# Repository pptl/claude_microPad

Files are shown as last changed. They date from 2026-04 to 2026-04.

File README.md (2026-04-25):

# Claude Ghost Macro Pad 專案計畫書 (V2.0 雙層鍵帽版)

這是一台專為 **Claude Code** 開發流程優化的左手專用巨集鍵盤。本版本採用 **雙層透明鍵帽 (Relegendable Keycaps)** 方案，透過紙條替換實現快速客製化，無需轉印與噴漆。

外殼採鬼魂造型，橙色3D列印外殼，頂部兩顆 RGB LED 作為「鬼眼」狀態燈。閑置時會顯示綠色，思考時會顯示藍色，等待使用者確認權限時會顯示紅色。

成品展示

### LED 狀態展示

| 待機（Idle）| 思考中（Thinking）| 等待授權（Permission Request）|
| :---: | :---: | :---: |
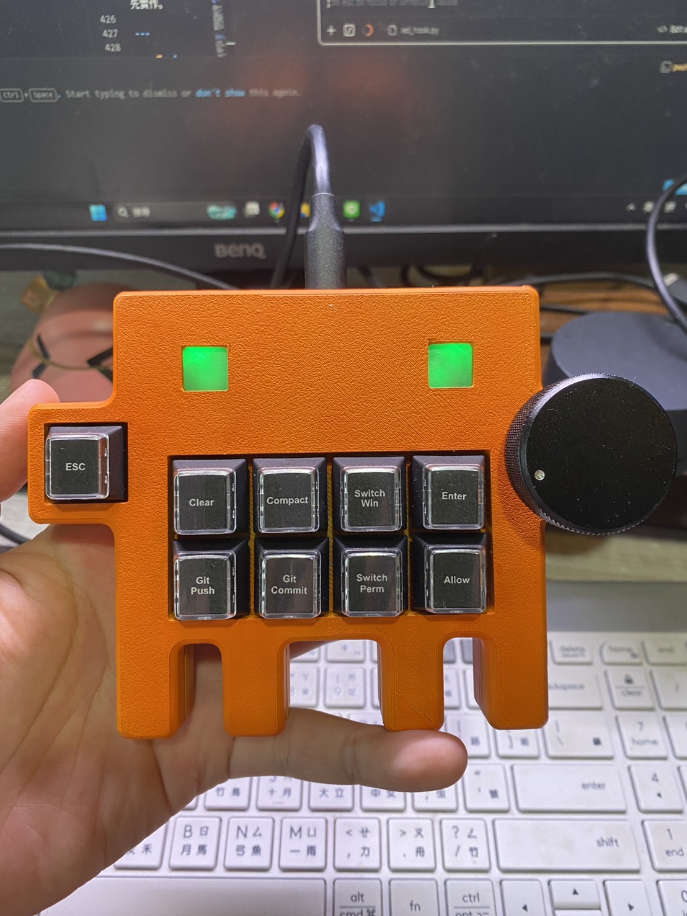
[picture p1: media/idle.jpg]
待機
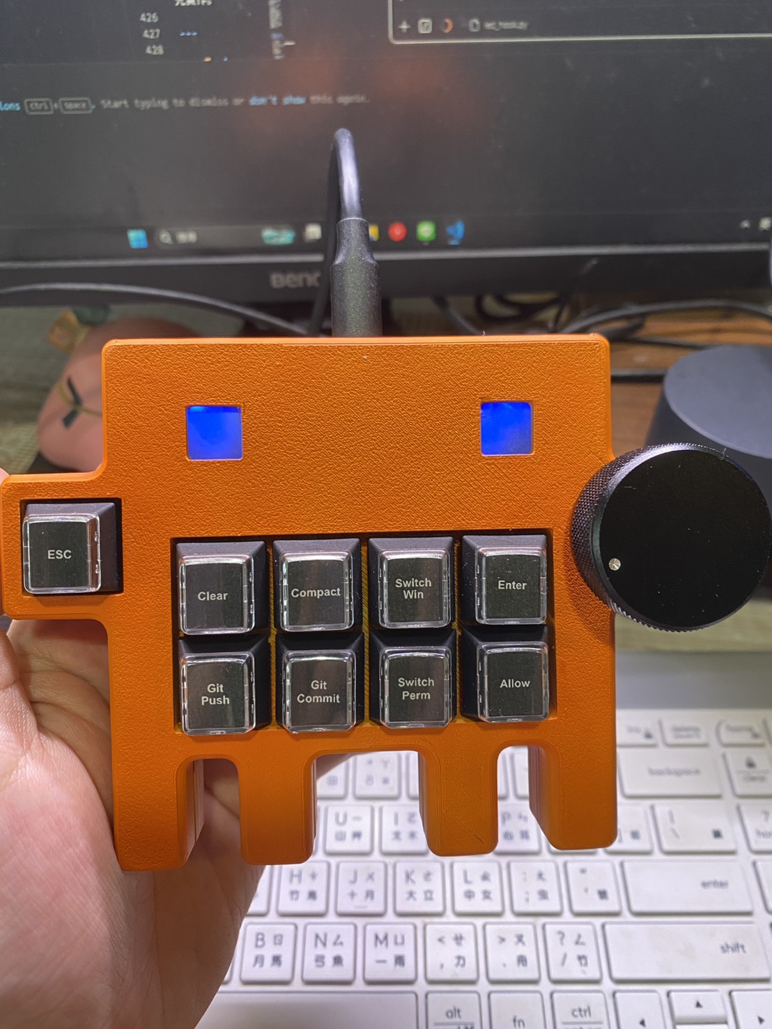
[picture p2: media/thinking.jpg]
思考中
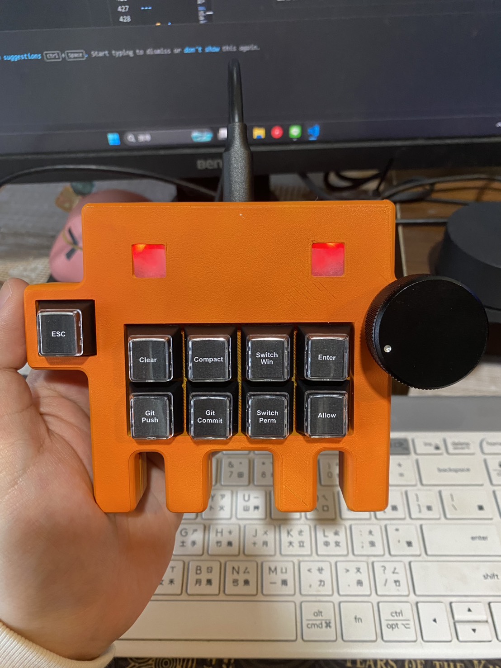
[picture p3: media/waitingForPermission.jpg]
等待授權
|  |  |  |
| 🟢 綠色 — 無操作 | 🔵 藍色 — Claude 執行工具中 | 🔴 紅色 — 等待使用者確認 |

---

## 🛠️ 一、 核心硬體採購清單

| 項目 | 購買規格 | 關鍵規格說明 | 備註 |
| :--- | :--- | :--- | :--- |
| **控制器** | **YD-RP2040** | Raspberry Pi Pico 相容 / Type-C 介面 | 核心開發板 |
| **指示燈** | **5mm RGB LED × 2** | 共陽極 / 四腳 / 透明 | 用於鬼魂眼睛，低電位觸發 |
| **機械軸** | **靜音系列** | 高特青檸軸 V3 / TTC 靜音紅 V3 | 靜音開發專用 |
| **鍵帽** | **雙層透明鍵帽** | 1U Relegendable Keycaps（共 9 顆） | 可拆卸頂蓋，內放紙條 |
| **編碼器** | **EC11 旋鈕** | D 型半軸 / 柄長 15mm / 帶開關 | 30 脈衝版本 |
| **旋鈕帽** | **大型全鋁** | 35×16mm 黑色滾花噴砂 | 直徑 35mm |
| **數據綫** | **TypeA to TypeC** | 長度按需求選購 |
| **線材** | **30 AWG 矽膠線** | 超軟、多色套裝 | 內部焊接理線專用 |
| **螺絲** | **M2 × 6mm 平頭螺絲** | 平頭（沉頭）/ 不鏽鋼或黑色 | 上下蓋固定用 |
| **止滑貼片** | **自黏橡膠腳墊 × 6** | 圓形或方形均可 | 底部墊高及止滑 |

---

## ⌨️ 二、 鍵盤佈局

按鍵位置示意圖（與 `keymap.h` 索引對應）：

```
[ 8 ]                                        [ 9 ] ← 旋鈕按下
         [ 0 ]    [ 1 ]    [ 2 ]    [ 3 ]
         [ 4 ]    [ 5 ]    [ 6 ]    [ 7 ]
```

全按鍵均為 1U 規格，目前預設按鍵功能如下：

| 索引 | 位置 | 功能 | 輸出 |
| :--- | :--- | :--- | :--- |
| **[8]** | 左上角獨立鍵 | ESC | ESC |
| **[9]** | 右上角旋鈕按下 | Enter | Enter |
| **[0]** | 矩陣上排 1 | Clear 對話 | `/clear` + Enter |
| **[1]** | 矩陣上排 2 | Compact 對話 | `/compact` + Enter |
| **[2]** | 矩陣上排 3 | Switch Window | Win+Tab |
| **[3]** | 矩陣上排 4 | Enter | Enter |
| **[4]** | 矩陣下排 1 | Git Push | `/gitPush` + Enter |
| **[5]** | 矩陣下排 2 | Git Commit | `/gitCommit` + Enter |
| **[6]** | 矩陣下排 3 | Change Permission Mode | Shift+Tab |
| **[7]** | 矩陣下排 4 | Allow | `allow` + Enter |
| — | 旋鈕旋轉 | 捲動 | ↑ / ↓ |

---

## 🔌 三、 電路設計

### WOKWI 可查看電路設計圖

將 `diagram.json` 的內容全部貼到 [WOKWI](https://wokwi.com) 上可以查看整體電路設計圖。

### GPIO 接腳對照（與韌體一致）

| GPIO | 功能 |
| :--- | :--- |
| GP0 | 按鍵 [8] — ESC |
| GP2 | LED1 R（左眼）|
| GP3 | LED1 G（左眼）|
| GP4 | LED1 B（左眼）|
| GP6 | 按鍵 [0] — Slash (`/`) |
| GP7 | 按鍵 [1] — Shift+Tab |
| GP8 | 按鍵 [4] — /gitPush |
| GP9 | 按鍵 [5] — claude |
| GP16 | 按鍵 [2] — Win+Tab |
| GP17 | 按鍵 [3] — Enter |
| GP18 | 按鍵 [7] — /compact |
| GP19 | 按鍵 [6] — /clear |
| GP20 | Encoder CLK |
| GP21 | Encoder DT |
| GP22 | 按鍵 [9] — Encoder SW (ESC) |
| GP26 | LED2 B（右眼）|
| GP27 | LED2 G（右眼）|
| GP28 | LED2 R（右眼）|

### LED 接線（共陽極）

- 最長腳（COM）→ 3.3V
- R、G 腳各串 **220Ω** 電阻後接 GPIO
- B 腳串 **68Ω** 電阻後接 GPIO（藍光 Vf 較高，需降低電阻）
- 軟體邏輯：`LOW` = 亮，`HIGH` = 滅

### 去耦電容（實體焊接）

手邊有 3 顆 **10µF** 電容，分別焊接於：
- LED1 電源入口旁（3.3V ↔ GND）
- LED2 電源入口旁（3.3V ↔ GND）
- 編碼器旁（3.3V ↔ GND）

防止 LED 切換時的 Ground Bounce 干擾按鍵與編碼器訊號。

### 關鍵尺寸限制

旋鈕中心至 Enter 鍵中心距離必須 **> 27mm**，避免 35mm 旋鈕帽碰撞。

---

## 💡 四、 LED 狀態指示

兩顆鬼眼 LED 即時反映 Claude Code 的工作狀態：

| 狀態 | 顏色 | 說明 |
| :--- | :--- | :--- |
| Idle（待機）| 🟢 綠色 | 開機預設、無操作、任務被使用者中斷（ESC）或拒絕授權 |
| Thinking（思考中）| 🔵 藍色 | Claude 正在執行工具 |
| Completed（完成）| 🟢 綠色 | 任務完成、回覆結束或 `/compact` 壓縮完畢 |
| Waiting（等待授權）| 🔴 紅色 | 等待使用者批准工具使用請求（PermissionRequest）|
| Error（問題）| 🔴 紅色 | 工具失敗、API 錯誤 |

---

## 💻 五、 安裝方法與步驟

### 步驟一：燒錄韌體（Arduino IDE）

1. 安裝 **Arduino IDE**（1.8 或 2.x）

2. 開啟 Preferences，在 **Additional Boards Manager URLs** 加入：
   ```
   https://github.com/earlephilhower/arduino-pico/releases/download/global/package_rp2040_index.json
   ```

3. 至 **Tools → Board → Boards Manager**，搜尋並安裝 `Raspberry Pi RP2040 Boards`

4. 至 **Sketch → Include Library → Manage Libraries**，搜尋並安裝 `Adafruit TinyUSB Library`

5. **Tools 設定：**
   - Board：`Raspberry Pi Pico`
   - USB Stack：`Adafruit TinyUSB`

6. 開啟 `firmware/claude_macropad/claude_macropad.ino`

7. **燒錄方式：** 按住 YD-RP2040 上的 **BOOT** 按鈕後插上 USB，放開後裝置會顯示為隨身碟，在 Arduino IDE 按 **Upload** 即可。

8. 燒錄成功後，鬼眼 LED 會閃爍三次藍光，然後轉為綠色待機。

### 步驟二：安裝 Python 依賴

```bash
pip install pyserial
```

### 步驟三：設定 COM Port

1. 插上 Macro Pad，開啟 **裝置管理員 → 連接埠 (COM 和 LPT)**，找到 RP2040 對應的 COM 編號

   > **快速辨識方法：** 在 Python 執行以下指令，找到 VID `0x239A`（Adafruit）的裝置即是 RP2040：
   > ```python
   > import serial.tools.list_ports
   > for p in serial.tools.list_ports.comports():
   >     print(p.device, hex(p.vid) if p.vid else "N/A", p.description)
   > ```

2. 修改 `hooks/led_hook.py` 第 19 行，填入實際 COM 編號：
   ```python
   PORT = "COM8"  # 依實際裝置調整
   ```

### 步驟四：設定 Claude Code Hooks

`led_hook.py` **沒有固定存放路徑**，可以放在任何位置，但必須確保 `~/.claude/settings.json` 裡的路徑與實際位置一致。

將以下內容加入 `~/.claude/settings.json`。`led_hook.py` 建議存放至全域 `~/.claude/scripts/` 資料夾，路徑需與本機使用者名稱一致（將 `USER_NAME` 替換為自己的帳號名稱）：

```json
{
  "hooks": {
    "UserPromptSubmit":   [{"matcher": "", "hooks": [{"type": "command", "command": "py C:\\Users\\USER_NAME\\.claude\\scripts\\led_hook.py"}]}],
    "PreToolUse":         [{"matcher": "", "hooks": [{"type": "command", "command": "py C:\\Users\\USER_NAME\\.claude\\scripts\\led_hook.py"}]}],
    "PostToolUse":        [{"matcher": "", "hooks": [{"type": "command", "command": "py C:\\Users\\USER_NAME\\.claude\\scripts\\led_hook.py"}]}],
    "Stop":               [{"matcher": "", "hooks": [{"type": "command", "command": "py C:\\Users\\USER_NAME\\.claude\\scripts\\led_hook.py"}]}],
    "PostToolUseFailure": [{"matcher": "", "hooks": [{"type": "command", "command": "py C:\\Users\\USER_NAME\\.claude\\scripts\\led_hook.py"}]}],
    "StopFailure":        [{"matcher": "", "hooks": [{"type": "command", "command": "py C:\\Users\\USER_NAME\\.claude\\scripts\\led_hook.py"}]}],
    "PermissionDenied":   [{"matcher": "", "hooks": [{"type": "command", "command": "py C:\\Users\\USER_NAME\\.claude\\scripts\\led_hook.py"}]}],
    "Notification":       [{"matcher": "", "hooks": [{"type": "command", "command": "py C:\\Users\\USER_NAME\\.claude\\scripts\\led_hook.py"}]}],
    "PermissionRequest":  [{"matcher": "", "hooks": [{"type": "command", "command": "py C:\\Users\\USER_NAME\\.claude\\scripts\\led_hook.py"}]}],
    "PostCompact":        [{"matcher": "", "hooks": [{"type": "command", "command": "py C:\\Users\\USER_NAME\\.claude\\scripts\\led_hook.py"}]}]
  }
}
```

> **注意：** Windows 使用 `py` 啟動器（上方範例），macOS / Linux 改用 `python3`。若移動了 `led_hook.py`，記得同步更新 settings.json 裡的路徑。

#### 偵錯：確認 Hook 是否正常運作

Hook 執行時會將收到的事件記錄至 `hooks/debug.log`。若 LED 無反應，可查看此檔案確認 Hook 是否有被觸發：

```bash
# 查看最後 10 筆事件
tail -10 d:/projects/claude_microPad/hooks/debug.log   # 原始專案路徑
# 或（若已移至全域）
tail -10 "C:/Users/USER_NAME/.claude/scripts/debug.log"
```

若 log 有內容但 LED 仍無反應，通常是 COM Port 設定錯誤或裝置未連接。

---

## 🎛️ 六、 自訂按鍵（keymap.h）

所有按鍵功能集中定義在 `firmware/claude_macropad/keymap.h`，**只需編輯此檔案，重新上傳韌體即可生效**，不需改動主程式。

### 按鍵索引對照

```
[ 8 ]                                        [ 9 ] ← 旋鈕按下
         [ 0 ]    [ 1 ]    [ 2 ]    [ 3 ]
         [ 4 ]    [ 5 ]    [ 6 ]    [ 7 ]
```

### 兩種按鍵模式

**模式一：組合鍵（BTN_KEYS）** — 送出單次按鍵或組合鍵

```c
const uint8_t BTN_KEYS[10][3] = {
  {SLASH, 0,      0},  // [0] /
  {SHIFT, TAB,    0},  // [1] Shift+Tab
  {WIN,   TAB,    0},  // [2] Win+Tab
  {ENTER, 0,      0},  // [3] Enter
  ...
};
```

**模式二：文字巨集（BTN_MACROS）** — 逐字輸出一串字元

```c
const char* BTN_MACROS[10] = {
  "/clear\n\n",     // [0] 輸出 /clear 後按兩次 Enter
  "/compact\n\n",   // [1] 輸出 /compact 後按兩次 Enter
  "",               // [2] 空字串 → 使用 BTN_KEYS
  "",               // [3] 空字串 → 使用 BTN_KEYS
  "/gitPush\n\n",   // [4] 輸出 /gitPush 後按兩次 Enter
  "/gitCommit\n\n", // [5] 輸出 /gitCommit 後按兩次 Enter
  "",               // [9] 空字串 → 使用 BTN_KEYS（旋鈕按下 = Enter）
  ...
};
```

> 若 `BTN_MACROS[i]` 非空字串，優先執行巨集，忽略 `BTN_KEYS[i]`。

### 可用按鍵常數

| 類別 | 常數 | 說明 |
| :--- | :--- | :--- |
| 修飾鍵 | `CTRL` `SHIFT` `ALT` `WIN` | Ctrl / Shift / Alt / Win |
| 方向鍵 | `UP` `DOWN` `LEFT` `RIGHT` | 上 / 下 / 左 / 右 |
| 特殊鍵 | `ENTER` `ESC` `TAB` `SPACE` `DEL` `BACKSPACE` `SLASH` | 常用功能鍵 |
| 字母鍵 | `L('a')` ~ `L('z')` | 例如 `L('e')` = E 鍵 |
| 數字鍵 | `N0` ~ `N9` | 例如 `N5` = 數字 5 |

> ⚠️ 不可直接用 `'c'` 或 `5`，ASCII 碼 ≠ USB HID 按鍵碼。

### 範例：改成自己的快捷鍵

```c
// 把 [3] 改成 Ctrl+Shift+P（命令選單）
{CTRL, SHIFT, L('p')},  // [3]

// 把 [6] 改成輸出自訂命令並送出
"/mycommand\n\n",  // [6] BTN_MACROS

// 把 [7] 改成單獨數字鍵
{N5, 0, 0},  // [7] BTN_KEYS（記得把 BTN_MACROS[7] 清空為 ""）
```

修改後，在 Arduino IDE 重新上傳韌體即可。

---

## ⚠️ 七、 製作提醒

1. **旋鈕高度差：** 雙層鍵帽比一般鍵帽略高，若旋鈕帽太矮難以轉動，可在旋鈕底部墊入 1–2mm 墊圈。
2. **標籤防褪色：** 有透明蓋保護，但長時間日光照射仍會褪色，建議多印幾份備用。
3. **線路固定：** 外殼半透明，內部焊接建議使用熱縮套管或熱熔膠固定，讓內視效果整齊。
4. **標籤尺寸：** 11mm × 13mm，上方功能名稱，下方小字快捷鍵，建議使用相片紙或名片紙。專案已附上可直接列印的 `Keycap_Labels_Print.pdf`，裁切後直接放入鍵帽即可。
5. **中文輸入法注意：** 巨集中的 `\n` 在開啟中文輸入法時可能被吃掉一個，建議使用 `\n\n` 確保指令送出。

---

## 📁 八、 專案檔案結構

```
claude_microPad/
├── README.md                          # 本文件
├── CLAUDE.md                          # Claude Code 專案指引
├── diagram.json                       # Wokwi 電路模擬圖
├── 按鈕佈局.drawio                     # 按鍵佈局設計圖（Draw.io）
├── Keycap_Labels_Print.pdf            # 🖨️ 鍵帽標籤列印檔（直接列印、裁切即可使用）
├── media/                             # 圖片、影片、GIF 媒體素材
│   ├── 按鈕佈局.jpg                   # 按鍵佈局匯出圖
│   ├── 成品展示_gif.gif               # 成品展示動圖
│   ├── 成品展示_pic.jpg               # 成品展示靜態圖
│   ├── fidgetToy.gif                  # 解壓玩具展示動圖
│   ├── demo.mp4                       # 成品展示影片
│   ├── idle.jpg                       # LED 狀態：待機
│   ├── thinking.jpg                   # LED 狀態：思考中
│   ├── waitingForPermission.jpg       # LED 狀態：等待授權
│   └── Gemini_Generated_Image_uxtut7uxtut7uxtu.png
├── firmware/
│   └── claude_macropad/
│       ├── claude_macropad.ino        # Arduino 韌體主程式（勿需修改）
│       └── keymap.h                   # ✏️ 按鍵自訂設定（在這裡修改）
└── hooks/
    └── led_hook.py                    # Claude Code Hook 腳本（設定 COM port）
```

---

---

## 🤖 九、 自訂 Slash Command — `/gitCommit`

本專案內建自訂 Claude Code 指令 `/gitCommit`，對應鍵盤上的 **[5]** 號按鍵。

### 功能說明

按下按鍵後，Claude Code 會自動：

1. **平行**收集 `git status`、`git diff HEAD`、`git log --oneline -5`、`git stash list`
2. 產出一份**繁體中文**的變更摘要（每個檔案說明改了什麼、為什麼），並建議符合此 repo 慣例的英文 commit 訊息
3. 顯示目前 git 帳號與分支，**等待用戶確認**後才執行寫入
4. 逐一 `git add` 相關檔案（避免加入敏感檔），再以 HEREDOC 執行 `git commit`
5. 回報最新 commit hash

> 收到確認之前，不會執行任何 git 寫入操作。

**例外處理：**
- 無變更 → 告知工作目錄乾淨
- 偵測到 `.env`、`*secret*` 等敏感檔 → 警告並略過
- pre-commit hook 失敗 → **不使用 `--amend`**，修正後建立全新 commit
- 殘留 Merge conflict 標記 → 中斷並警告

### 指令檔案位置

```
.claude/commands/gitCommit.md   ← 本專案專屬（僅此專案有效）
```

---

## 🤖 十、 自訂 Slash Command — `/gitPush`

本專案內建自訂 Claude Code 指令 `/gitPush`，對應鍵盤上的 **[9]** 號按鍵（旋鈕按下）。

### 功能說明

`/gitPush` 專責將已 commit 的變更推送至遠端，執行流程如下：

**第一階段：預檢**
- 若工作區有未提交的變更，**立即中斷**並提示先完成 commit 或 `git stash`
- 若分支尚無遠端追蹤（首次推送），跳至「首次推送流程」

**第二階段：狀態彙整**
- 顯示目前 git 帳號、分支，以及所有待推送的 commit 清單
- 若目前分支為 `main` / `master`，額外顯示保護分支警告

**第三階段：合併策略**

列出待推送 commit 後，提供三個選項：

| 選項 | 說明 |
| :--- | :--- |
| **1. 合併推送（預設）** | Squash 成單一 commit，自動建立備份分支 `backup/<branch>-<YYYYMMDD>` |
| **2. 編輯訊息後合併推送** | 同上，但允許手動修改 commit 訊息 |
| **3. 原樣推送** | 直接 `git push`，保留所有 commit |

> 若只有 1 個待推送 commit，跳過合併選項，直接確認推送。

**第四階段：執行**
- 合併推送：`git reset --soft <基準點>` → `git commit` → `git push`
- 原樣推送：直接 `git push`
- 推送失敗時，告知可用備份分支復原

**首次推送流程（NO_UPSTREAM）：**
確認後執行 `git push -u origin <branch>`，不執行 Squash。

> 收到確認之前，不會執行任何 git 寫入操作。永遠不使用 `--no-verify` 或 `--force`。

### 指令檔案位置

```
.claude/commands/gitPush.md   ← 本專案專屬（僅此專案有效）
```

### 改為全域使用（所有專案都能用）

Claude Code 的 Slash Command 有兩個存放位置：

| 位置 | 路徑 | 有效範圍 |
| :--- | :--- | :--- |
| **專案層級** | `<專案目錄>/.claude/commands/` | 僅限該專案 |
| **全域層級** | `~/.claude/commands/` | 所有專案 |

將指令升級為全域只需複製檔案：

**Windows（PowerShell）**
```powershell
Copy-Item "d:\projects\claude_microPad\.claude\commands\gitCommit.md" "$env:USERPROFILE\.claude\commands\gitCommit.md"
Copy-Item "d:\projects\claude_microPad\.claude\commands\gitPush.md" "$env:USERPROFILE\.claude\commands\gitPush.md"
```

**macOS / Linux（Bash）**
```bash
cp /path/to/claude_microPad/.claude/commands/gitCommit.md ~/.claude/commands/gitCommit.md
cp /path/to/claude_microPad/.claude/commands/gitPush.md ~/.claude/commands/gitPush.md
```

複製完成後，在任何專案的 Claude Code 中輸入 `/gitCommit` 或 `/gitPush`，即可使用。

---

## 🔮 十一、 未來功能規劃

以下為日後可考慮加入的功能方向，尚未實作。

### 1. 按鍵編輯桌面軟體

目前自訂按鍵需要修改 `keymap.h` 並重新燒錄韌體。未來可透過 CircuitPython 的 USB 隨身碟機制，讓 Macro Pad 插上電腦後直接以讀寫設定檔的方式更新按鍵配置，無需 IDE；規模更大時可考慮 [Vial](https://get.vial.today/) 相容層，提供現成的跨平台 GUI。

### 2. 軌跡球滑鼠控制

在外殼整合軌跡球，搭配 **PMW3360** 感測器（SPI 直連 RP2040）與 34mm 撞球，實現左手不離鍵盤的滑鼠控制。外殼需重新設計以容納球座，建議作為獨立的 V3.0 硬體版本規劃。

### 3. 小型顯示螢幕

加入 **SSD1306 OLED（128×64，I2C）** 顯示目前按鍵模式、Claude 連線狀態或最後執行的指令。RP2040 剩餘 GPIO 足夠支援；若需要彩色顯示可升級至 ST7789 TFT，但功耗與接線複雜度會提高。三項功能中投資報酬率最高，建議優先實作。

---

## 🧸 十二、 Claude Code 吉祥物解壓小玩具

本專案附帶一款以 Claude Code 吉祥物為外形設計的解壓小玩具（Fidget Toy），可自行 3D 列印。

解壓玩具展示

**模型下載：** [MyMiniFactory — Claude Code Mascot Fidget Toy](https://www.myminifactory.com/object/3d-print-claude-code-mascot-fidget-toy-791307)

---

*文件更新日期：2026-04-25*

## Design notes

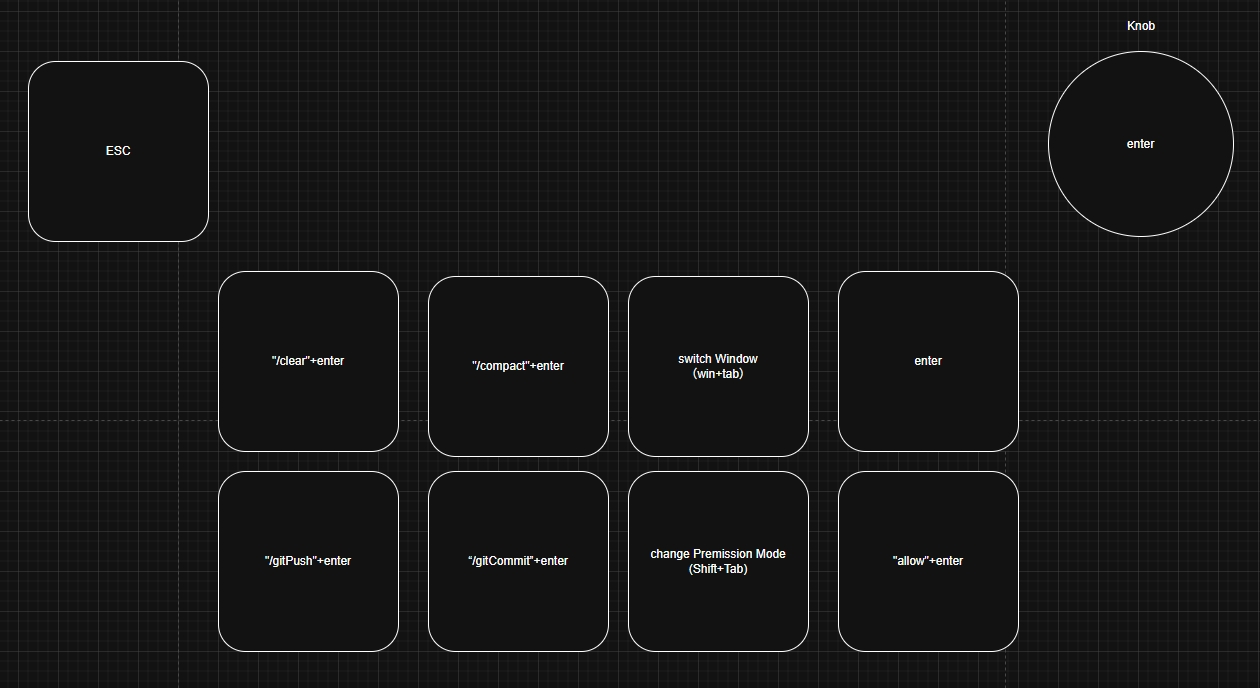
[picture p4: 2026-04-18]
media/按鈕佈局.jpg

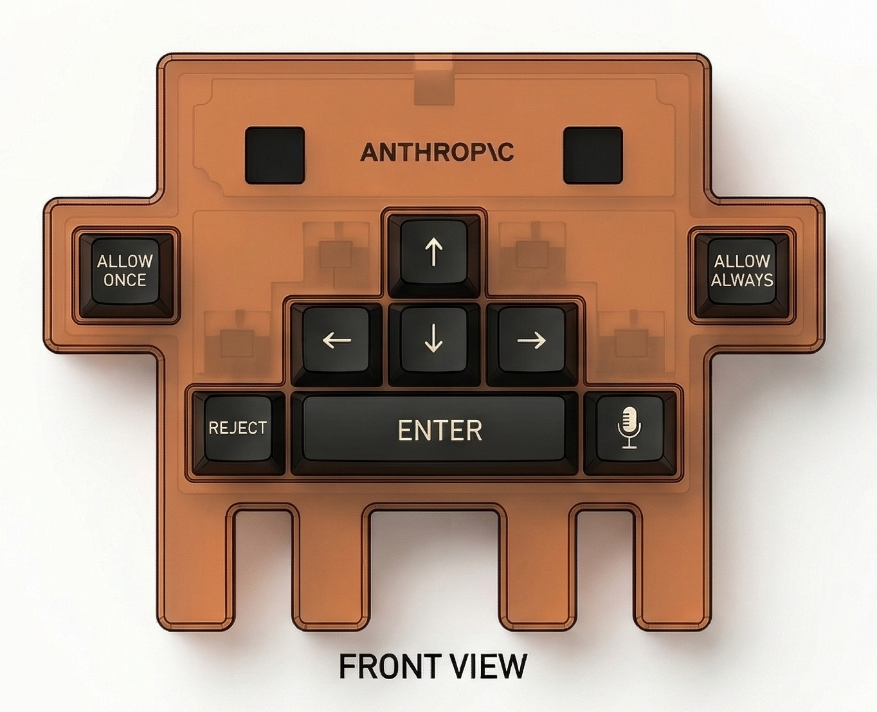
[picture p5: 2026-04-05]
media/Gemini_Generated_Image_uxtut7uxtut7uxtu.png

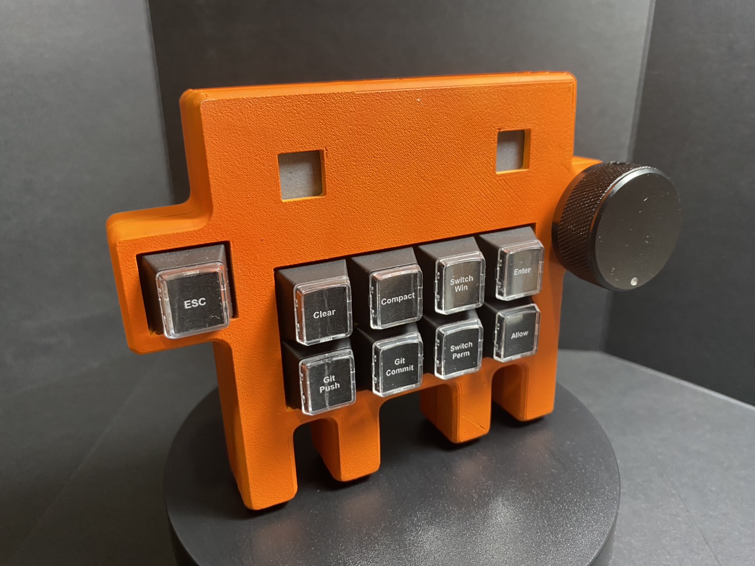
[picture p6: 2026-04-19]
media/成品展示_pic.jpg

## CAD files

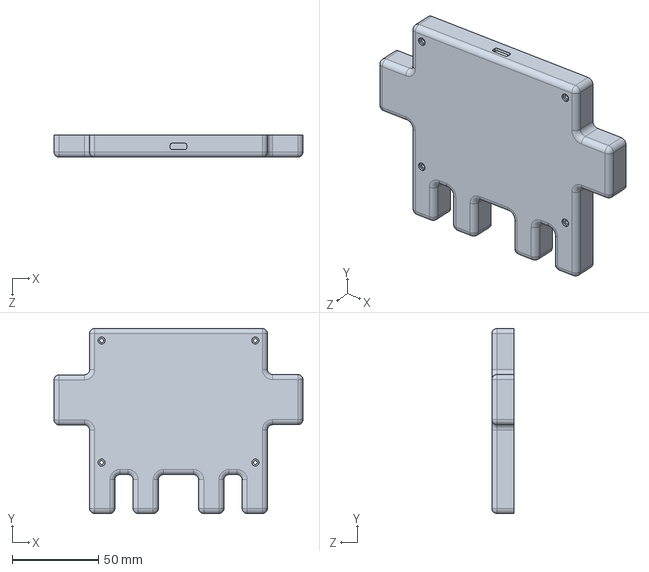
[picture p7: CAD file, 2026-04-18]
modal/bottom.SLDPRT
144.7 x 107.6 x 13.0 mm

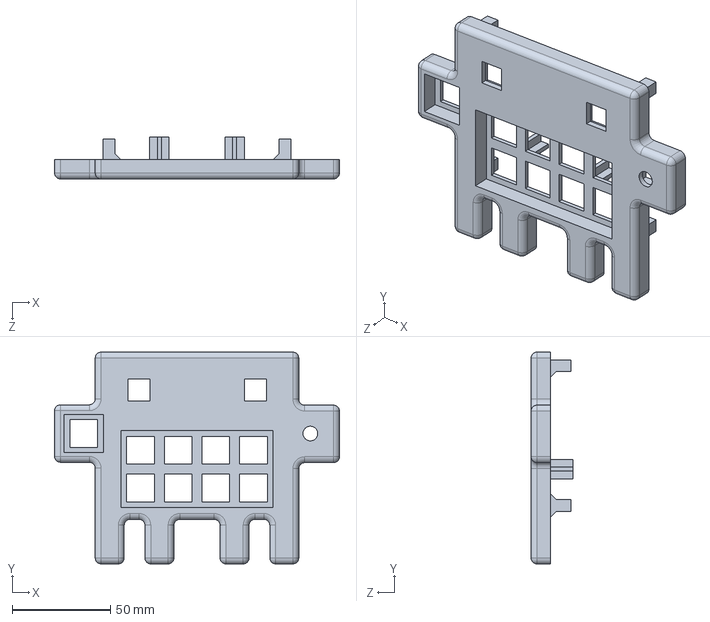
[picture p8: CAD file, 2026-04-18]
modal/top.SLDPRT
144.7 x 107.6 x 21.3 mm

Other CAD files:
modal/bottom.STL
modal/top.STL

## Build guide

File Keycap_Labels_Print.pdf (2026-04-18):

Keycap labels · 11mm × 13mm · black on white reverse (cut & apply) | A4 · 13 labels × 4 copies = 52 pieces
ESC | Clear | Compact

Switch
Win

Enter

Git
Push

Git
Commit

Switch
Perm
Allow | Allow | Allow | Allow

Always
Allow
ESC | Clear | Compact

Switch
Win

Enter

Git
Push

Git
Commit

Switch
Perm
Allow | Allow | Allow | Allow

Always
Allow
ESC | Clear | Compact

Switch
Win

Enter

Git
Push

Git
Commit

Switch
Perm
Allow | Allow | Allow | Allow

Always
Allow
ESC | Clear | Compact

Switch
Win

Enter

Git
Push

Git
Commit

Switch
Perm
Allow | Allow | Allow | Allow

Always
Allow

Print at 100% — disable “fit to page”. Verify with a ruler: each tile should measure 11 × 13 mm.
Cut along the light grey corner ticks. Two-word labels are stacked on two lines. Four copies printed — use spares if you mis-cut.

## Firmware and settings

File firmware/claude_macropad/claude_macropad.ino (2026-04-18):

/*
  Claude Ghost Macro Pad V1.0 
  適用於 YD-RP2040 (IDE 設定請選 Raspberry Pi Pico)
*/

#include <Adafruit_TinyUSB.h>
#include "keymap.h"

// --- 1. 手動建立 Keyboard 模擬物件 ---
uint8_t const desc_hid_report[] = { TUD_HID_REPORT_DESC_KEYBOARD() };
Adafruit_USBD_HID usb_hid;

class KeyboardEmulator {
public:
  void begin() {
    usb_hid.setPollInterval(2);
    usb_hid.setReportDescriptor(desc_hid_report, sizeof(desc_hid_report));
    usb_hid.begin();
  }

  // 一次送出最多 3 個按鍵的完整組合報告（同時處理 modifier + 一般鍵）
  void sendCombo(const uint8_t keys[3]) {
    if (!usb_hid.ready()) return;
    uint8_t mod = 0;
    uint8_t keycodes[6] = {0};
    int ki = 0;
    for (int k = 0; k < 3; k++) {
      if (keys[k] == 0) continue;
      if (keys[k] >= 0xE0 && keys[k] <= 0xE7) {
        mod |= (1 << (keys[k] - 0xE0));  // modifier key
      } else {
        if (ki < 6) keycodes[ki++] = keys[k];
      }
    }
    usb_hid.keyboardReport(0, mod, keycodes);
  }

  // 等待 USB 端點就緒後再送釋放報告，確保主機能收到 key-up
  void releaseAll() {
    unsigned long t = millis();
    while (!usb_hid.ready() && (millis() - t) < 20) delay(1);
    usb_hid.keyboardRelease(0);
  }

  // 逐字輸出字串（支援 a-z A-Z 0-9 / space \n -）
  void typeString(const char* str) {
    for (int i = 0; str[i] != '\0'; i++) {
      uint8_t key = 0, mod = 0;
      char c = str[i];
      if      (c >= 'a' && c <= 'z') { key = HID_KEY_A + (c - 'a'); }
      else if (c >= 'A' && c <= 'Z') { key = HID_KEY_A + (c - 'A'); mod = 0x02; }
      else if (c >= '1' && c <= '9') { key = HID_KEY_1 + (c - '1'); }
      else if (c == '0')  { key = HID_KEY_0;      }
      else if (c == '\n') { delay(200); key = 0x28; }
      else if (c == ' ')  { key = HID_KEY_SPACE;   }
      else if (c == '/')  { key = HID_KEY_SLASH;   }
      else if (c == '-')  { key = HID_KEY_MINUS;   }
      if (key == 0) continue;
      unsigned long t = millis();
      while (!usb_hid.ready() && (millis() - t) < 100) delay(1);
      uint8_t keys[6] = {key, 0, 0, 0, 0, 0};
      if (!usb_hid.keyboardReport(0, mod, keys)) {
        delay(20);
        usb_hid.keyboardReport(0, mod, keys);
      }
      delay(30);
      releaseAll();
      delay(30);
    }
  }
} Keyboard;

// --- 3. 硬體腳位定義 ---
const int LED_PINS[6] = {2, 3, 4, 28, 27, 26}; // R1 G1 B1 R2 G2 B2
const int BTN_PINS[10] = {6, 7, 16, 17, 8, 9, 19, 18, 0, 22};
const int ENC_CLK = 20;
const int ENC_DT  = 21;

// --- 4. Debounce 狀態 ---
const unsigned long DEBOUNCE_MS = 20;

bool rawBtn[10];       // 目前讀到的原始電位
bool stableBtn[10];    // 經過 debounce 後的穩定狀態
unsigned long debounceTimer[10];

// 旋鈕 - 正交狀態機 + 穩定時間 debounce
// 新狀態必須保持穩定 ENC_STABLE_MS 毫秒才算有效轉換，防止彈跳累積
uint8_t encState   = 0;  // 最後確認的穩定狀態
uint8_t encPending = 0;  // 目前讀到、尚待確認的狀態
int8_t  encCount   = 0;
unsigned long encStableTimer = 0;
const unsigned long ENC_STABLE_MS  = 5;  // 信號穩定門檻（毫秒）
const int8_t        STEPS_PER_DETENT = 4; // EC11 標準值；若一格觸發兩次改成 2

// 正交解碼表：ENC_TABLE[舊狀態][新狀態] = +1 (CW) / -1 (CCW) / 0 (無效跳變)
const int8_t ENC_TABLE[4][4] = {
//  新: 00  01  10  11
    {  0, +1, -1,  0 }, // 舊 00
    { -1,  0,  0, +1 }, // 舊 01
    { +1,  0,  0, -1 }, // 舊 10
    {  0, -1, +1,  0 }, // 舊 11
};

// --- 5. LED ---
void setLeds(bool r1, bool g1, bool b1, bool r2, bool g2, bool b2) {
  bool v[6] = {r1, g1, b1, r2, g2, b2};
  for (int i = 0; i < 6; i++) digitalWrite(LED_PINS[i], v[i] ? LOW : HIGH);
}

void applyState(char cmd) {
  switch (cmd) {
    case 'T': setLeds(0,0,1, 0,0,1); break; // Blue  (Thinking)
    case 'C': setLeds(0,1,0, 0,1,0); break; // Green (Completed)
    case 'E': setLeds(1,0,0, 1,0,0); break; // Red   (Error)
    case 'I': setLeds(0,1,0, 0,1,0); break; // Green (Idle)
  }
}

// --- 6. Setup ---
void setup() {
  for (int i = 0; i < 6; i++) { pinMode(LED_PINS[i], OUTPUT); digitalWrite(LED_PINS[i], HIGH); }

  for (int i = 0; i < 10; i++) {
    pinMode(BTN_PINS[i], INPUT_PULLUP);
    rawBtn[i]    = HIGH;
    stableBtn[i] = HIGH;
    debounceTimer[i] = 0;
  }

  pinMode(ENC_CLK, INPUT_PULLUP);
  pinMode(ENC_DT,  INPUT_PULLUP);
  encState = encPending = (digitalRead(ENC_CLK) << 1) | digitalRead(ENC_DT);

  Keyboard.begin();
  Serial.begin(9600);

  // 等待 USB 枚舉完成（最多 2 秒），確保動畫在 USB 穩定後執行
  unsigned long t0 = millis();
  while (!TinyUSBDevice.mounted() && (millis() - t0 < 2000)) delay(1);

  // 啟動成功的視覺反饋：閃爍三次藍燈（250ms 週期，肉眼清晰可見）
  for (int i = 0; i < 3; i++) {
    setLeds(0,0,1, 0,0,1); delay(250);
    setLeds(0,0,0, 0,0,0); delay(250);
  }
  applyState('I');
}

// --- 7. Loop ---
void loop() {
  unsigned long now = millis();

  // 處理序列埠指令
  if (Serial.available()) {
    char cmd = (char)Serial.read();
    applyState(cmd);
  }

  // 處理按鈕（時間基礎 debounce）
  for (int i = 0; i < 10; i++) {
    bool raw = digitalRead(BTN_PINS[i]);

    // 偵測到電位變化，重設計時器
    if (raw != rawBtn[i]) {
      rawBtn[i] = raw;
      debounceTimer[i] = now;
    }

    // 超過穩定時間後，更新穩定狀態並觸發動作
    if ((now - debounceTimer[i]) >= DEBOUNCE_MS && raw != stableBtn[i]) {
      stableBtn[i] = raw;
      if (raw == LOW) {                    // 按下
        if (BTN_MACROS[i][0] != '\0') {
          Keyboard.typeString(BTN_MACROS[i]);
        } else {
          Keyboard.sendCombo(BTN_KEYS[i]);
        }
      } else {                             // 放開
        Keyboard.releaseAll();
      }
    }
  }

  // 處理旋鈕（正交狀態機 + 穩定時間 debounce）
  uint8_t rawEnc = (digitalRead(ENC_CLK) << 1) | digitalRead(ENC_DT);

  if (rawEnc != encState) {
    if (rawEnc != encPending) {
      encPending = rawEnc;
      encStableTimer = now;
    }

    if ((now - encStableTimer) >= ENC_STABLE_MS) {
      int8_t movement = ENC_TABLE[encState][encPending];
      if (movement != 0) {
        encCount += movement;
      }
      encState = encPending;

      if (encCount >= STEPS_PER_DETENT) {
        uint8_t up[3] = {UP, 0, 0};
        Keyboard.sendCombo(up);
        Keyboard.releaseAll();
        encCount = 0;
      } else if (encCount <= -STEPS_PER_DETENT) {
        uint8_t dn[3] = {DOWN, 0, 0};
        Keyboard.sendCombo(dn);
        Keyboard.releaseAll();
        encCount = 0;
      }
    }
  }
}

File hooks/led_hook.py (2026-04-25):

"""
Claude Code Hook — LED Status Reporter
Reads hook event JSON from stdin, sends a single-byte command
to the RP2040 macro pad via USB CDC serial.

Commands:
  T = Thinking  (UserPromptSubmit, PreToolUse, PostToolUse)
  C = Completed (Stop with reason=completed)
  I = Idle      (user_interrupt, PermissionDenied)
  E = Error     (PostToolUseFailure, StopFailure, PermissionRequest, permission_prompt)

Setup:
  pip install pyserial
  Set PORT below to match your device (e.g. COM3, COM7).
"""

import sys
import json

PORT = "COM8"   # <-- Change this to match your RP2040's CDC serial port
BAUD = 9600

EVENT_MAP = {
    "UserPromptSubmit":    "T",
    "PreToolUse":          "T",
    "PostToolUse":         "T",   # stay blue until fully stopped
    "Stop":                "C",   # refined below for stop_reason
    "PostToolUseFailure":  "E",
    "StopFailure":         "E",
    "PermissionRequest":   "E",   # waiting for user approval → red
    "PermissionDenied":    "I",   # task terminated → idle green
    "PostCompact":         "C",   # compact finished → green
}

LOG = "d:/projects/claude_microPad/hooks/debug.log"

def main():
    try:
        data = json.load(sys.stdin)
    except Exception:
        sys.exit(0)

    # DEBUG: log all incoming payloads
    with open(LOG, "a", encoding="utf-8") as f:
        f.write(json.dumps(data) + "\n")

    event = data.get("hook_event_name", "")

    # Notification hook: permission_prompt → red (waiting for approval)
    if event == "Notification":
        if data.get("notification_type") == "permission_prompt":
            cmd = "E"
        else:
            sys.exit(0)
    else:
        cmd = EVENT_MAP.get(event)

    # Distinguish user-interrupted Stop from completed Stop
    if event == "Stop":
        stop_reason = data.get("stop_reason", "completed")
        if stop_reason == "user_interrupt":
            cmd = "I"  # Return to idle on manual interrupt

    # Tool interrupted by user (not a real error) → green
    if event == "PostToolUseFailure" and data.get("is_interrupt"):
        cmd = "C"

    if cmd is None:
        sys.exit(0)

    # Stop/PermissionDenied may race with in-flight T commands from parallel hooks.
    # A short delay lets them finish writing first so this green command wins.
    if event in ("Stop", "PermissionDenied", "StopFailure"):
        import time
        time.sleep(0.35)

    try:
        import serial
        with serial.Serial(PORT, BAUD, timeout=1) as s:
            s.write(cmd.encode())
    except Exception as e:
        # Never block Claude Code due to serial errors
        sys.stderr.write(f"[led_hook] serial error: {e}\n")

    sys.exit(0)


if __name__ == "__main__":
    main()

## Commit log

2026-04-05 保存相關檔案
2026-04-05 fix：修復模組使用錯誤以及部分邏輯bug
2026-04-06 feat：建模完成
    [Assem1.SLDASM, CE3S1PRO_bottom.3mf, CE3S1PRO_top.3mf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]
2026-04-18 feat：修復模型脆弱點及調整按鈕佈局
    [Assem1.SLDASM, CE3S1PRO_bottom.3mf, CE3S1PRO_top.3mf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]
2026-04-18 feat：調整按鍵佈局及 GPIO 表
    修正 GPIO 表 — 改為與韌體 claude_macropad.ino 實際腳位一致（GP2-4 LED1、GP6-9/16-19 按鍵、GP20-22 編碼器、GP26-28 LED2）
    更新按鍵佈局表 — 反映 keymap.h 目前實際功能（/gitPush、claude、/clear、/compact 等巨集）
    新增完整安裝步驟（第五節）— 從 Arduino IDE 設定、燒錄、pip install、COM port 設定到 Hooks 設定，逐步說明
    新增 keymap.h 自訂章節（第六節）— 說明按鍵索引、兩種模式（組合鍵 vs 文字巨集）、所有可用常數、修改範例
    更新檔案結構 — 加入 keymap.h，標注哪個檔案需要修改
    [claude_macropad.ino, led_hook.py]
2026-04-18 docs: 全面更新 README 並新增 gitPush slash command
    - 修正 GPIO 腳位表以符合韌體實際接線
    - 更新按鍵佈局對應 keymap.h 現況（巨集按鍵）
    - 新增完整安裝步驟章節（Arduino IDE、pyserial、COM port、Hooks）
    - 新增 keymap.h 自訂按鍵說明章節（組合鍵與文字巨集）
    - BOM 補充 M2 螺絲與止滑貼片
    - 新增 /gitPush 自訂 Slash Command 說明與全域化方法
    - 新增 .claude/commands/gitPush.md 指令定義檔
2026-04-18 docs: update README with gitCommit section and revised gitPush flow
2026-04-18 docs: update LED hook path guidance and fix COM port in led_hook.py
    - Update README step 3/4 with VID detection method, global scripts path, and debug instructions
    - Fix COM port from COM4 to COM8 in hooks/led_hook.py
    - Update 按鈕佈局.drawio with corrected key label positions
    [led_hook.py]
2026-04-18 feat: update keymap layout — swap gitPush/gitCommit, remap knob to Enter
2026-04-18 docs: add keycap label print PDF and update README
2026-04-25 docs: reorganize media assets and fix LED hook event handling
    [led_hook.py]
2026-04-25 docs: update LED status table and hook config example in README
